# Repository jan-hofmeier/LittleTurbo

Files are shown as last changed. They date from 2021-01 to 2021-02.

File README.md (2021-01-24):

# Little Turbo

This card plugs into the co-processor slot of the Amiga 2000 and allows you to clock your 68000 or 68010 at 14Mhz. It also supports 2MB of SRAM of wich up to 1.75MB can be used as Fast Ranger RAM, like the Memory card of the original German A2000. The SRAM can run at the full 14Mhz with zero wait states.
It can also serve just as an Memory Expansion, without the 14Mhz stuff. In this case the CPU can stay in the sockel of the mainboard
The memory is mapped at `$C0000`. If you have a Rev. 4 B2000 this will overlap the onboard 512K "Slow RAM". 
The unused Part of the 2MB of SRAM can be used to emulate a Kickstart ROM up to 1MB.

The Layout of the Slot Connector was taken from SukkoPera OpenAmiga2000CoproAdapter

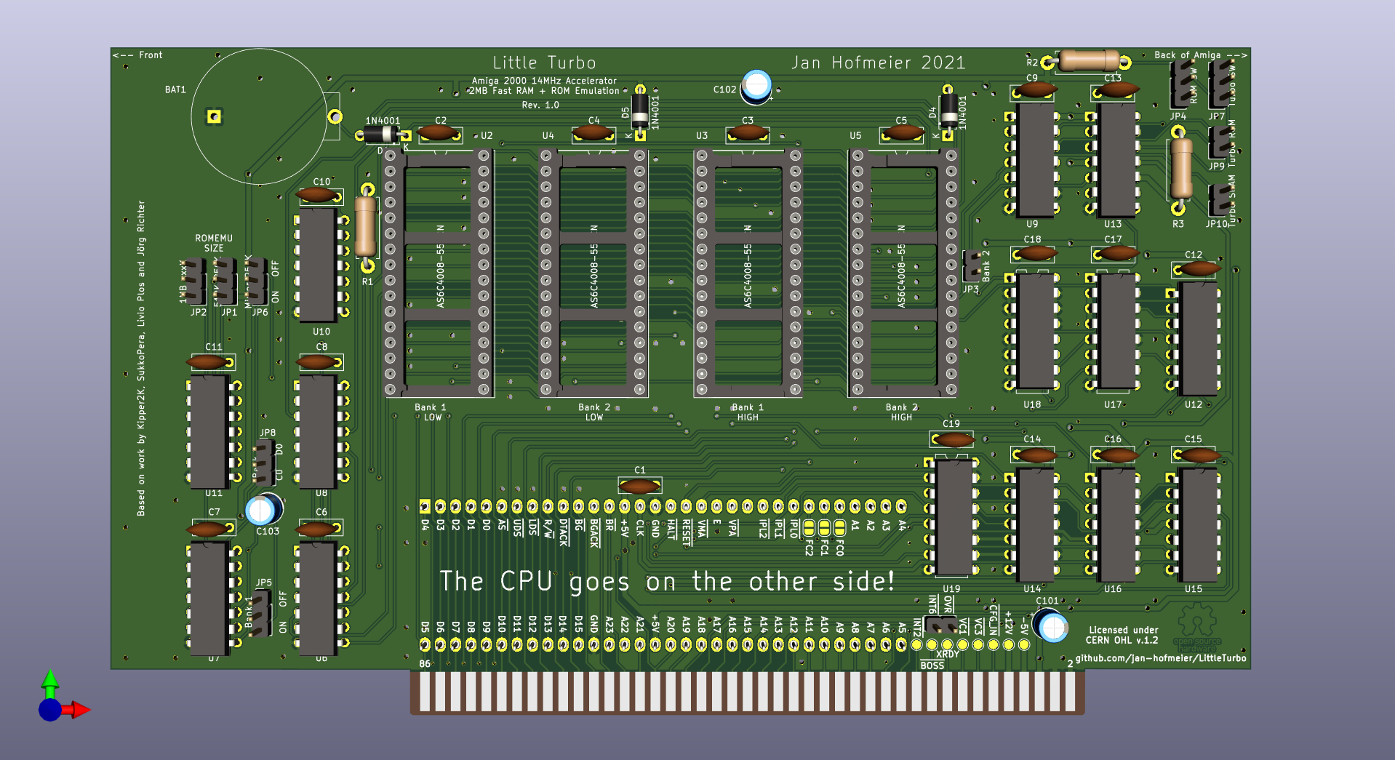
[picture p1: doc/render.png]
Board


### State of the Project

The PCB is done, next up is verifying that it works as intended.

### Installation
**Please be very careful when plugging this board** in the co-processor slot: there is an arrow on the board, **it must point to the back of the Amiga**. Plugging this adapter backwards will damage your CPU/accelerator card, as some pins of the CPU slot carry +12V!

### Parts
https://www.digikey.de/short/4795fv

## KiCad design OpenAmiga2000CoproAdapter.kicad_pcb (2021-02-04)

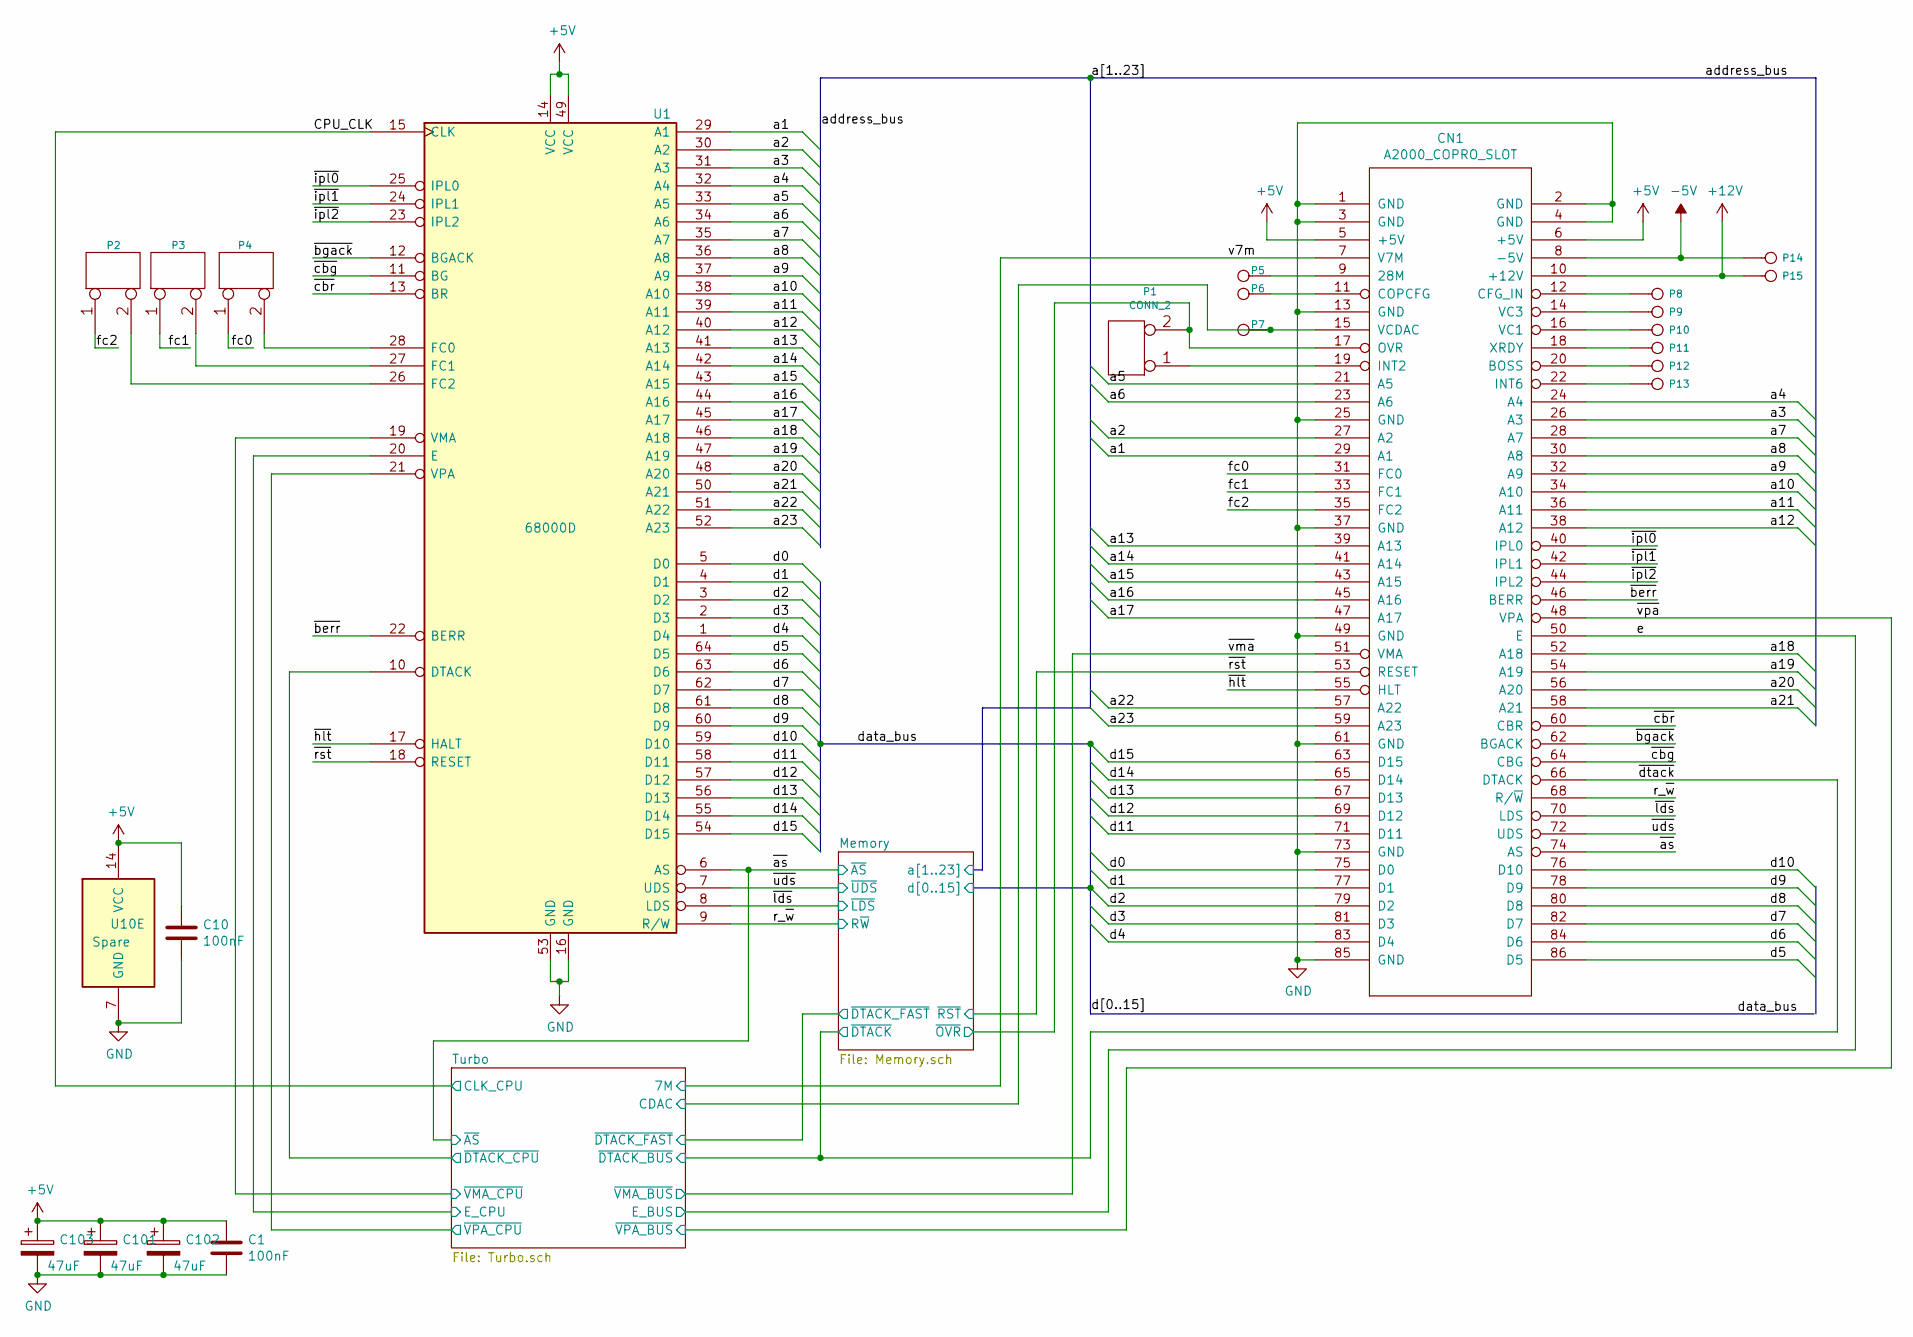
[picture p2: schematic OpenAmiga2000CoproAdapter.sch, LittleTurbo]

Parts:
C1, C10: 100nF; C_Disc_D7.0mm_W2.5mm_P5.00mm
C101, C102, C103: 47uF; CP_Radial_D5.0mm_P2.50mm
CN1: A2000_COPRO_SLOT
P1: CONN_2; PinHeader_1x02_P2.54mm_Vertical
P2, P3, P4: CONN_2; SolderJumper-2_P1.3mm_Open_RoundedPad1.0x1.5mm
P5, P6, P7, P8, P9, P10, P11, P12, P13, P14, P15: CONN_1; TestPoint_Pad_D1.5mm
U1: 68000D; DIP-64_W22.86mm_Socket_LongPads
U10: Spare; DIP-14_W7.62mm

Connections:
+5V: C1.1, C10.1, C101.1, C102.1, C103.1, CN1.5 (+5V), CN1.6 (+5V), U1.14 (VCC), U1.49 (VCC), U10.14 (VCC); also elsewhere on the board
+12V: CN1.10 (+12V), P15.1
-5V: CN1.8 (-5V), P14.1
/CPU_CLK: U1.15 (CLK); also elsewhere on the board
/Memory/~OVR: CN1.17 (OVR), P1.2 (PM); also elsewhere on the board
/Turbo/CDAC: CN1.15 (VCDAC), P7.1; also elsewhere on the board
/Turbo/E_CPU: U1.20 (E); also elsewhere on the board
/Turbo/~DTACK_CPU: U1.10 (DTACK); also elsewhere on the board
/Turbo/~VMA_CPU: U1.19 (VMA); also elsewhere on the board
/Turbo/~VPA_CPU: U1.21 (VPA); also elsewhere on the board
/a1: CN1.29 (A1), U1.29 (A1); also elsewhere on the board
/a2: CN1.27 (A2), U1.30 (A2); also elsewhere on the board
/a3: CN1.26 (A3), U1.31 (A3); also elsewhere on the board
/a4: CN1.24 (A4), U1.32 (A4); also elsewhere on the board
/a5: CN1.21 (A5), U1.33 (A5); also elsewhere on the board
/a6: CN1.23 (A6), U1.34 (A6); also elsewhere on the board
/a7: CN1.28 (A7), U1.35 (A7); also elsewhere on the board
/a8: CN1.30 (A8), U1.36 (A8); also elsewhere on the board
/a9: CN1.32 (A9), U1.37 (A9); also elsewhere on the board
/a10: CN1.34 (A10), U1.38 (A10); also elsewhere on the board
/a11: CN1.36 (A11), U1.39 (A11); also elsewhere on the board
/a12: CN1.38 (A12), U1.40 (A12); also elsewhere on the board
/a13: CN1.39 (A13), U1.41 (A13); also elsewhere on the board
/a14: CN1.41 (A14), U1.42 (A14); also elsewhere on the board
/a15: CN1.43 (A15), U1.43 (A15); also elsewhere on the board
/a16: CN1.45 (A16), U1.44 (A16); also elsewhere on the board
/a17: CN1.47 (A17), U1.45 (A17); also elsewhere on the board
/a18: CN1.52 (A18), U1.46 (A18); also elsewhere on the board
/a19: CN1.54 (A19), U1.47 (A19); also elsewhere on the board
/a20: CN1.56 (A20), U1.48 (A20); also elsewhere on the board
/a21: CN1.58 (A21), U1.50 (A21); also elsewhere on the board
/a22: CN1.57 (A22), U1.51 (A22); also elsewhere on the board
/a23: CN1.59 (A23), U1.52 (A23); also elsewhere on the board
/d0: CN1.75 (D0), U1.5 (D0); also elsewhere on the board
/d1: CN1.77 (D1), U1.4 (D1); also elsewhere on the board
/d2: CN1.79 (D2), U1.3 (D2); also elsewhere on the board
/d3: CN1.81 (D3), U1.2 (D3); also elsewhere on the board
/d4: CN1.83 (D4), U1.1 (D4); also elsewhere on the board
/d5: CN1.86 (D5), U1.64 (D5); also elsewhere on the board
/d6: CN1.84 (D6), U1.63 (D6); also elsewhere on the board
/d7: CN1.82 (D7), U1.62 (D7); also elsewhere on the board
/d8: CN1.80 (D8), U1.61 (D8); also elsewhere on the board
/d9: CN1.78 (D9), U1.60 (D9); also elsewhere on the board
/d10: CN1.76 (D10), U1.59 (D10); also elsewhere on the board
/d11: CN1.71 (D11), U1.58 (D11); also elsewhere on the board
/d12: CN1.69 (D12), U1.57 (D12); also elsewhere on the board
/d13: CN1.67 (D13), U1.56 (D13); also elsewhere on the board
/d14: CN1.65 (D14), U1.55 (D14); also elsewhere on the board
/d15: CN1.63 (D15), U1.54 (D15); also elsewhere on the board
/e: CN1.50 (E); also elsewhere on the board
/fc0: CN1.31 (FC0), P4.1
/fc1: CN1.33 (FC1), P3.1
/fc2: CN1.35 (FC2), P2.1
/r_~w: CN1.68 (R/~W), U1.9 (R/W); also elsewhere on the board
/v7m: CN1.7 (V7M); also elsewhere on the board
/~as: CN1.74 (AS), U1.6 (AS); also elsewhere on the board
/~berr: CN1.46 (BERR), U1.22 (BERR)
/~bgack: CN1.62 (BGACK), U1.12 (BGACK)
/~cbg: CN1.64 (CBG), U1.11 (BG)
/~cbr: CN1.60 (CBR), U1.13 (BR)
/~dtack: CN1.66 (DTACK); also elsewhere on the board
/~hlt: CN1.55 (HLT), U1.17 (HALT)
/~ipl0: CN1.40 (IPL0), U1.25 (IPL0)
/~ipl1: CN1.42 (IPL1), U1.24 (IPL1)
/~ipl2: CN1.44 (IPL2), U1.23 (IPL2)
/~lds: CN1.70 (LDS), U1.8 (LDS); also elsewhere on the board
/~rst: CN1.53 (RESET), U1.18 (RESET); also elsewhere on the board
/~uds: CN1.72 (UDS), U1.7 (UDS); also elsewhere on the board
/~vma: CN1.51 (VMA); also elsewhere on the board
/~vpa: CN1.48 (VPA); also elsewhere on the board
GND: C1.2, C10.2, C101.2, C102.2, C103.2, CN1.1 (GND), CN1.2 (GND), CN1.3 (GND), CN1.4 (GND), CN1.13 (GND), CN1.25 (GND), CN1.37 (GND), CN1.49 (GND), CN1.61 (GND), CN1.73 (GND), CN1.85 (GND), U1.16 (GND), U1.53 (GND), U10.7 (GND); also elsewhere on the board
unnamed: CN1.9 (28M), P5.1
unnamed: CN1.11 (COPCFG), P6.1
unnamed: CN1.12 (CFG_IN), P8.1
unnamed: CN1.14 (VC3), P9.1
unnamed: CN1.16 (VC1), P10.1
unnamed: CN1.18 (XRDY), P11.1
unnamed: CN1.19 (INT2), P1.1
unnamed: CN1.20 (BOSS), P12.1
unnamed: CN1.22 (INT6), P13.1
unnamed: P2.2 (PM), U1.26 (FC2)
unnamed: P3.2 (PM), U1.27 (FC1)
unnamed: P4.2 (PM), U1.28 (FC0)

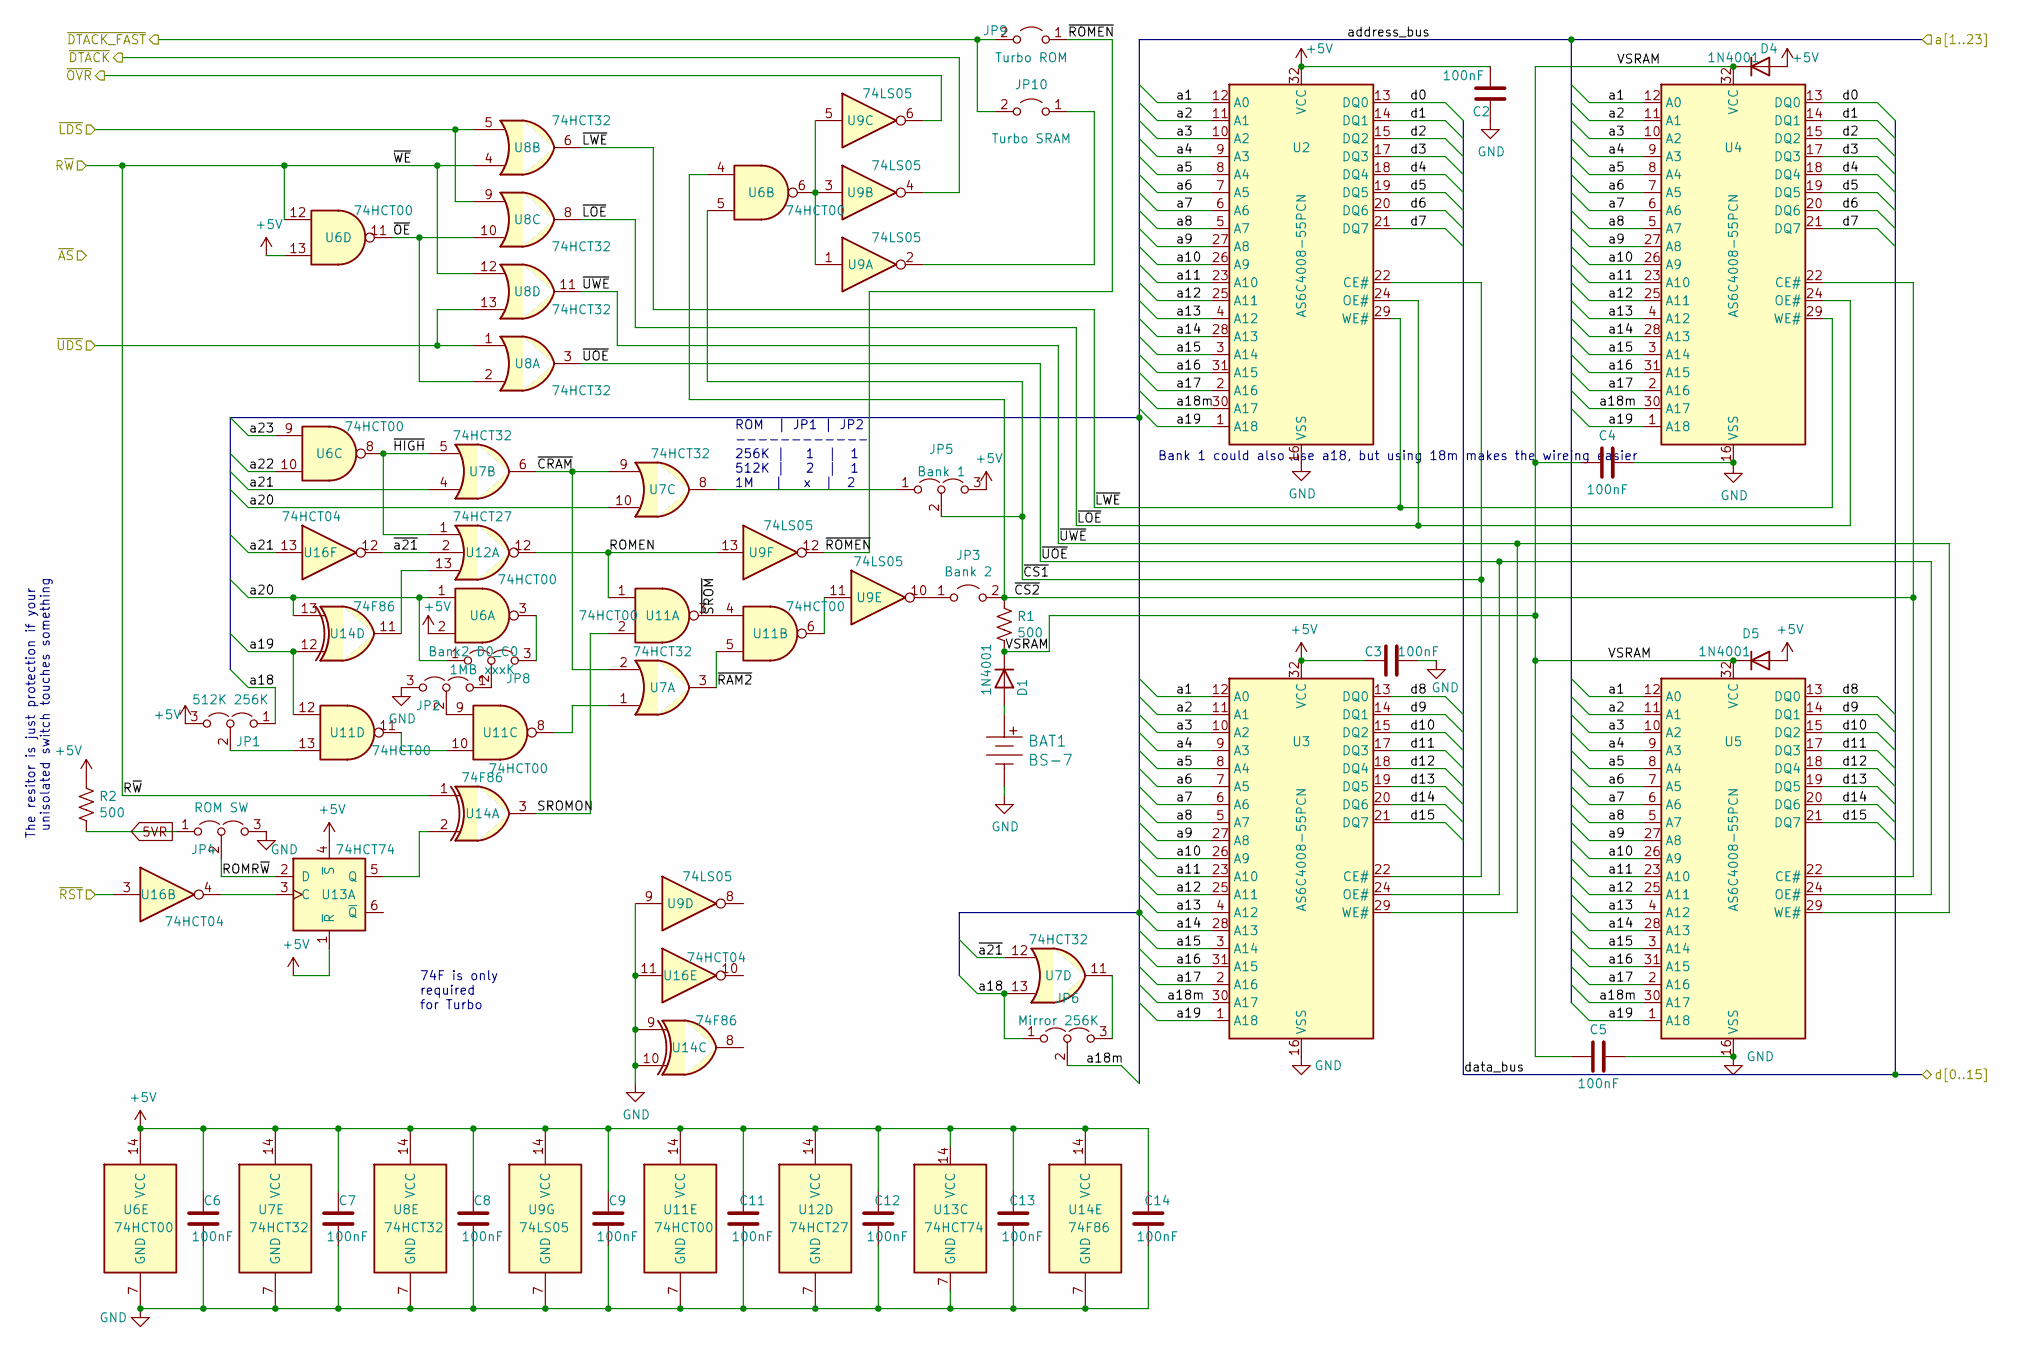
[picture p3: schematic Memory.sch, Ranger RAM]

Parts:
BAT1: BS-7; Battery_Holder_Coin_2032_BS-7; MPN BS-7; Digi-Key_PN BS-7-ND
C2, C3, C4, C5, C6, C7, C8, C9, C11, C12, C13, C14: 100nF; C_Disc_D7.0mm_W2.5mm_P5.00mm
D1, D4, D5: 1N4001; D_A-405_P7.62mm_Horizontal
JP1: 512K 256K; PinHeader_1x03_P2.54mm_Vertical
JP2: 1MB xxxK; PinHeader_1x03_P2.54mm_Vertical
JP3: Bank 2; PinHeader_1x02_P2.54mm_Vertical
JP4: ROM SW; PinHeader_1x03_P2.54mm_Vertical
JP5: Bank 1; PinHeader_1x03_P2.54mm_Vertical
JP6: Mirror 256K; PinHeader_1x03_P2.54mm_Vertical
JP8: Bank2 D0_C0; PinHeader_1x03_P2.54mm_Vertical
JP9: Turbo ROM; PinHeader_1x02_P2.54mm_Vertical
JP10: Turbo SRAM; PinHeader_1x02_P2.54mm_Vertical
R1, R2: 500; R_Axial_DIN0411_L9.9mm_D3.6mm_P12.70mm_Horizontal
U2, U3, U4, U5: AS6C4008-55PCN; DIP-32_W15.24mm_Socket
U6, U11: 74HCT00; DIP-14_W7.62mm
U7, U8: 74HCT32; DIP-14_W7.62mm
U9: 74LS05; DIP-14_W7.62mm
U12: 74HCT27; DIP-14_W7.62mm
U13: 74HCT74; DIP-14_W7.62mm
U14: 74F86; DIP-14_W7.62mm
U16: 74HCT04; DIP-14_W7.62mm

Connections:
5VR: JP4.1 (A), R2.2; also elsewhere on the board
+5V: C2.2, C3.2, C6.1, C7.1, C8.1, C9.1, C11.1, C12.1, C13.1, C14.1, D4.2 (A), D5.2 (A), JP1.3 (B), JP5.3 (B), R2.1, U2.32 (VCC), U3.32 (VCC), U6.2, U6.13, U6.14 (VCC), U7.14 (VCC), U8.14 (VCC), U9.14 (VCC), U11.14 (VCC), U12.14 (VCC), U13.1 (~R), U13.4 (~S), U13.14 (VCC), U14.14 (VCC); also elsewhere on the board
/Memory/ROMEN: U9.13, U11.1, U12.12
/Memory/ROMR~W: JP4.2 (C), U13.2 (D)
/Memory/SROMON: U11.2, U14.3
/Memory/VSRAM: C4.2, C5.2, D1.1 (K), D4.1 (K), D5.1 (K), R1.2, U4.32 (VCC), U5.32 (VCC)
/Memory/a18m: JP6.2 (C), U2.30 (A17), U3.30 (A17), U4.30 (A17), U5.30 (A17)
/Memory/~CRAM: U7.2, U7.6, U7.9
/Memory/~CS1: JP5.2 (C), U2.22 (CE#), U3.22 (CE#), U6.5
/Memory/~CS2: JP3.2 (B), R1.1, U4.22 (CE#), U5.22 (CE#), U6.4
/Memory/~DTACK_FAST: JP9.2 (B), JP10.2 (B); also elsewhere on the board
/Memory/~HIGH: U6.8, U7.5, U12.1
/Memory/~LOE: U2.24 (OE#), U4.24 (OE#), U8.8
/Memory/~LWE: U2.29 (WE#), U4.29 (WE#), U8.6
/Memory/~OE: U6.11, U8.2, U8.10
/Memory/~OVR: U9.6; also elsewhere on the board
/Memory/~RAM2: U7.3, U11.5
/Memory/~ROMEN: JP9.1 (A), U9.12
/Memory/~SROM: U11.3, U11.4
/Memory/~UOE: U3.24 (OE#), U5.24 (OE#), U8.3
/Memory/~UWE: U3.29 (WE#), U5.29 (WE#), U8.11
/Memory/~a21: U7.12, U12.2, U16.12
/a1: U2.12 (A0), U3.12 (A0), U4.12 (A0), U5.12 (A0); also elsewhere on the board
/a2: U2.11 (A1), U3.11 (A1), U4.11 (A1), U5.11 (A1); also elsewhere on the board
/a3: U2.10 (A2), U3.10 (A2), U4.10 (A2), U5.10 (A2); also elsewhere on the board
/a4: U2.9 (A3), U3.9 (A3), U4.9 (A3), U5.9 (A3); also elsewhere on the board
/a5: U2.8 (A4), U3.8 (A4), U4.8 (A4), U5.8 (A4); also elsewhere on the board
/a6: U2.7 (A5), U3.7 (A5), U4.7 (A5), U5.7 (A5); also elsewhere on the board
/a7: U2.6 (A6), U3.6 (A6), U4.6 (A6), U5.6 (A6); also elsewhere on the board
/a8: U2.5 (A7), U3.5 (A7), U4.5 (A7), U5.5 (A7); also elsewhere on the board
/a9: U2.27 (A8), U3.27 (A8), U4.27 (A8), U5.27 (A8); also elsewhere on the board
/a10: U2.26 (A9), U3.26 (A9), U4.26 (A9), U5.26 (A9); also elsewhere on the board
/a11: U2.23 (A10), U3.23 (A10), U4.23 (A10), U5.23 (A10); also elsewhere on the board
/a12: U2.25 (A11), U3.25 (A11), U4.25 (A11), U5.25 (A11); also elsewhere on the board
/a13: U2.4 (A12), U3.4 (A12), U4.4 (A12), U5.4 (A12); also elsewhere on the board
/a14: U2.28 (A13), U3.28 (A13), U4.28 (A13), U5.28 (A13); also elsewhere on the board
/a15: U2.3 (A14), U3.3 (A14), U4.3 (A14), U5.3 (A14); also elsewhere on the board
/a16: U2.31 (A15), U3.31 (A15), U4.31 (A15), U5.31 (A15); also elsewhere on the board
/a17: U2.2 (A16), U3.2 (A16), U4.2 (A16), U5.2 (A16); also elsewhere on the board
/a18: JP1.1 (A), JP6.1 (A), U7.13; also elsewhere on the board
/a19: U2.1 (A18), U3.1 (A18), U4.1 (A18), U5.1 (A18), U11.12, U14.12; also elsewhere on the board
/a20: JP8.1 (A), U6.1, U7.10, U14.13; also elsewhere on the board
/a21: U7.4, U16.13; also elsewhere on the board
/a22: U6.10; also elsewhere on the board
/a23: U6.9; also elsewhere on the board
/d0: U2.13 (DQ0), U4.13 (DQ0); also elsewhere on the board
/d1: U2.14 (DQ1), U4.14 (DQ1); also elsewhere on the board
/d2: U2.15 (DQ2), U4.15 (DQ2); also elsewhere on the board
/d3: U2.17 (DQ3), U4.17 (DQ3); also elsewhere on the board
/d4: U2.18 (DQ4), U4.18 (DQ4); also elsewhere on the board
/d5: U2.19 (DQ5), U4.19 (DQ5); also elsewhere on the board
/d6: U2.20 (DQ6), U4.20 (DQ6); also elsewhere on the board
/d7: U2.21 (DQ7), U4.21 (DQ7); also elsewhere on the board
/d8: U3.13 (DQ0), U5.13 (DQ0); also elsewhere on the board
/d9: U3.14 (DQ1), U5.14 (DQ1); also elsewhere on the board
/d10: U3.15 (DQ2), U5.15 (DQ2); also elsewhere on the board
/d11: U3.17 (DQ3), U5.17 (DQ3); also elsewhere on the board
/d12: U3.18 (DQ4), U5.18 (DQ4); also elsewhere on the board
/d13: U3.19 (DQ5), U5.19 (DQ5); also elsewhere on the board
/d14: U3.20 (DQ6), U5.20 (DQ6); also elsewhere on the board
/d15: U3.21 (DQ7), U5.21 (DQ7); also elsewhere on the board
/r_~w: U6.12, U8.4, U8.12, U14.1; also elsewhere on the board
/~dtack: U9.4; also elsewhere on the board
/~lds: U8.5, U8.9; also elsewhere on the board
/~rst: U16.3; also elsewhere on the board
/~uds: U8.1, U8.13; also elsewhere on the board
GND: BAT1.Neg, C2.1, C3.1, C4.1, C5.1, C6.2, C7.2, C8.2, C9.2, C11.2, C12.2, C13.2, C14.2, JP2.3 (B), JP4.3 (B), U2.16 (VSS), U3.16 (VSS), U4.16 (VSS), U5.16 (VSS), U6.7 (GND), U7.7 (GND), U8.7 (GND), U9.7 (GND), U9.9, U11.7 (GND), U12.7 (GND), U13.7 (GND), U14.7 (GND), U14.9, U14.10, U16.11; also elsewhere on the board
unnamed: BAT1.Pos, D1.2 (A)
unnamed: JP1.2 (C), U11.13
unnamed: JP2.1 (A), JP8.2 (C)
unnamed: JP2.2 (C), U11.9
unnamed: JP3.1 (A), U9.10
unnamed: JP5.1 (A), U7.8
unnamed: JP6.3 (B), U7.11
unnamed: JP8.3 (B), U6.3
unnamed: JP10.1 (A), U9.2
unnamed: U6.6, U9.1, U9.3, U9.5
unnamed: U9.11, U11.6
unnamed: U7.1, U11.8
unnamed: U11.10, U11.11
unnamed: U12.13, U14.11
unnamed: U13.3 (C), U16.4
unnamed: U13.5 (Q), U14.2

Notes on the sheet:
ROM | JP1 | JP2 ------------ 256K | 1 | 1 512K | 2 | 1 1M | x | 2
Bank 1 could also use a18, but using 18m makes the wireing easier
74F is only required for Turbo
The resitor is just protection if your unisolated switch touches something

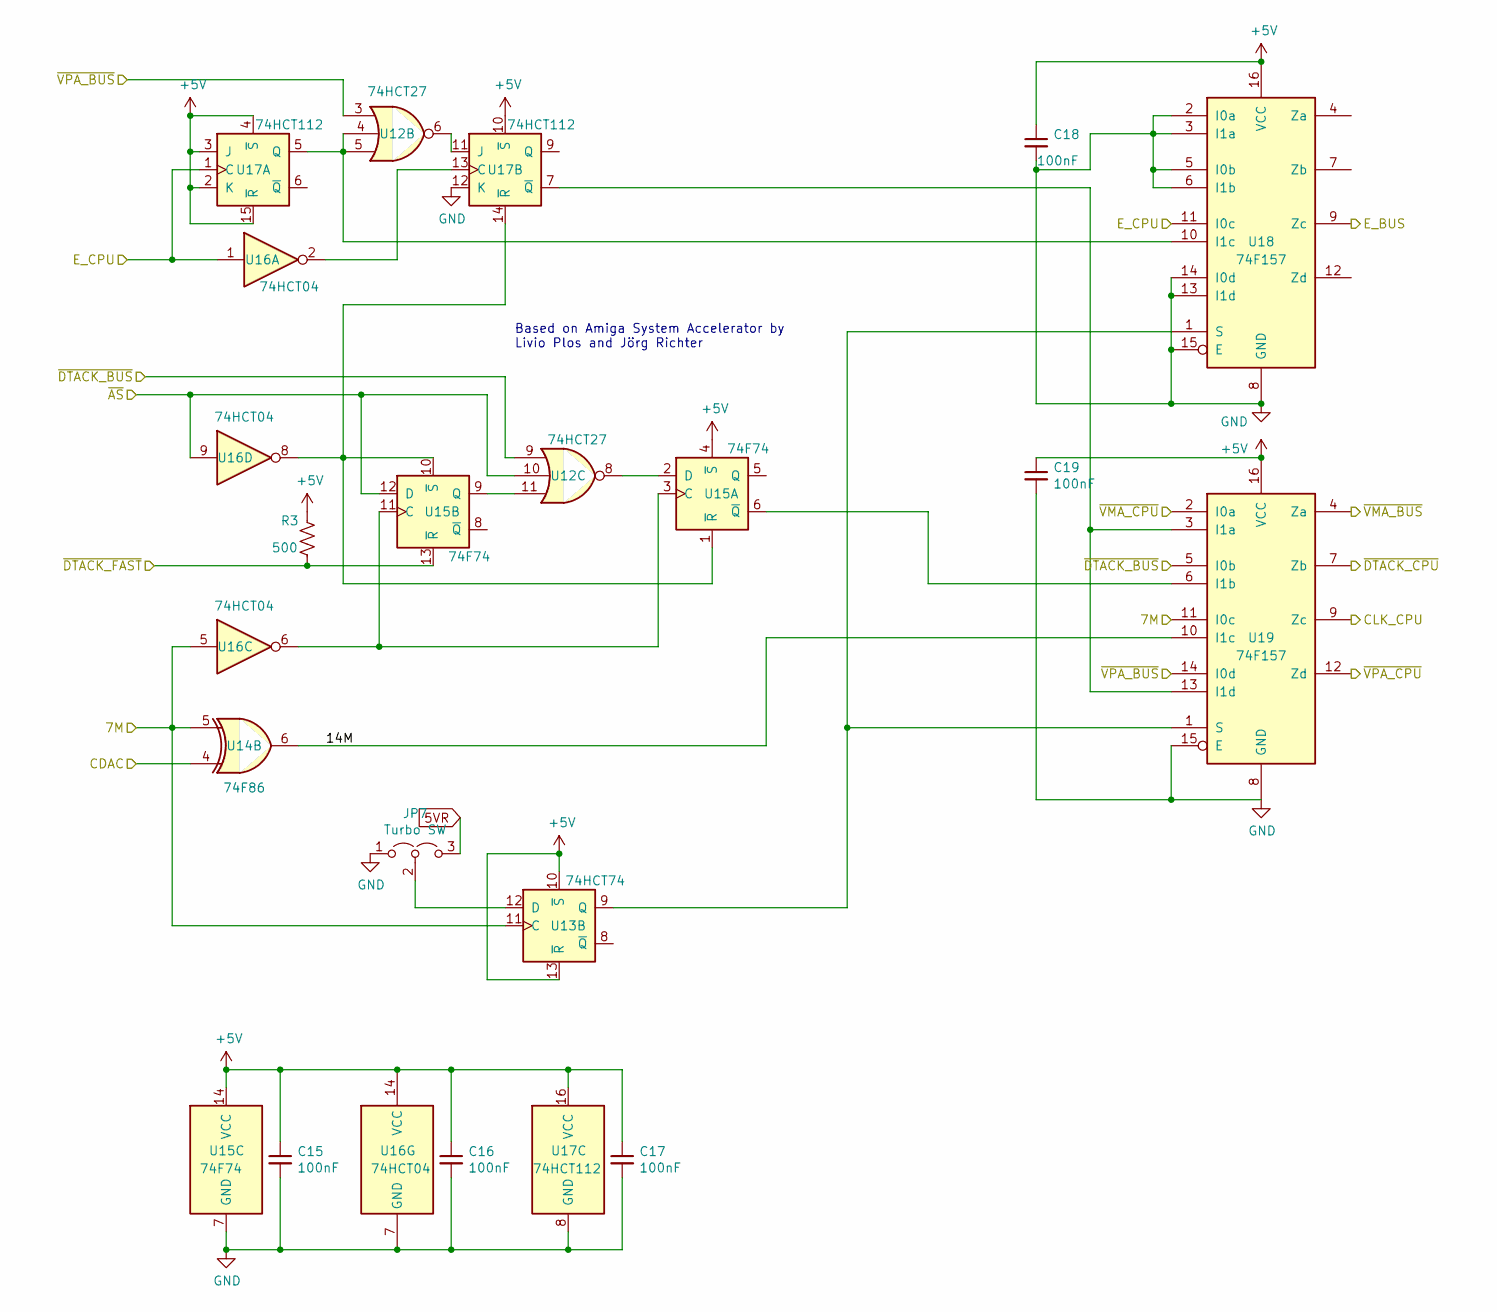
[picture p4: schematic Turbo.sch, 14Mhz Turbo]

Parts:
C15, C16, C17, C18, C19: 100nF; C_Disc_D7.0mm_W2.5mm_P5.00mm
JP7: Turbo SW; PinHeader_1x03_P2.54mm_Vertical
R3: 500; R_Axial_DIN0411_L9.9mm_D3.6mm_P12.70mm_Horizontal
U12: 74HCT27; DIP-14_W7.62mm
U13: 74HCT74; DIP-14_W7.62mm
U14: 74F86; DIP-14_W7.62mm
U15: 74F74; DIP-14_W7.62mm
U16: 74HCT04; DIP-14_W7.62mm
U17: 74HCT112; DIP-16_W7.62mm
U18, U19: 74F157; DIP-16_W7.62mm

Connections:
5VR: JP7.3 (B); also elsewhere on the board
+5V: C15.1, C16.1, C17.1, C18.1, C19.1, R3.1, U13.10 (~S), U13.13 (~R), U15.4 (~S), U15.14 (VCC), U16.14 (VCC), U17.2 (K), U17.3 (J), U17.4 (~S), U17.10 (~S), U17.15 (~R), U17.16 (VCC), U18.16 (VCC), U19.16 (VCC); also elsewhere on the board
/CPU_CLK: U19.9 (Zc); also elsewhere on the board
/Memory/~DTACK_FAST: R3.2, U15.13 (~R); also elsewhere on the board
/Turbo/14M: U14.6, U19.10 (I1c)
/Turbo/CDAC: U14.4; also elsewhere on the board
/Turbo/E_CPU: U16.1, U17.1 (C), U18.11 (I0c); also elsewhere on the board
/Turbo/~DTACK_CPU: U19.7 (Zb); also elsewhere on the board
/Turbo/~VMA_CPU: U19.2 (I0a); also elsewhere on the board
/Turbo/~VPA_CPU: U19.12 (Zd); also elsewhere on the board
/e: U18.9 (Zc); also elsewhere on the board
/v7m: U13.11 (C), U14.5, U16.5, U19.11 (I0c); also elsewhere on the board
/~as: U12.10, U15.12 (D), U16.9; also elsewhere on the board
/~dtack: U12.9, U19.5 (I0b); also elsewhere on the board
/~vma: U19.4 (Za); also elsewhere on the board
/~vpa: U12.3, U19.14 (I0d); also elsewhere on the board
GND: C15.2, C16.2, C17.2, C18.2, C19.2, JP7.1 (A), U15.7 (GND), U16.7 (GND), U17.8 (GND), U17.12 (K), U18.2 (I0a), U18.3 (I1a), U18.5 (I0b), U18.6 (I1b), U18.8 (GND), U18.13 (I1d), U18.14 (I0d), U18.15 (E), U19.8 (GND), U19.15 (E); also elsewhere on the board
unnamed: JP7.2 (C), U13.12 (D)
unnamed: U12.4, U12.5, U17.5 (Q), U18.10 (I1c)
unnamed: U12.6, U17.11 (J)
unnamed: U12.8, U15.2 (D)
unnamed: U12.11, U15.9 (Q)
unnamed: U13.9 (Q), U18.1 (S), U19.1 (S)
unnamed: U15.1 (~R), U15.10 (~S), U16.8, U17.14 (~R)
unnamed: U15.6 (~Q), U19.6 (I1b)
unnamed: U15.3 (C), U15.11 (C), U16.6
unnamed: U16.2, U17.13 (C)
unnamed: U17.7 (~Q), U19.3 (I1a), U19.13 (I1d)

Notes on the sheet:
Based on Amiga System Accelerator by Livio Plos and Jörg Richter

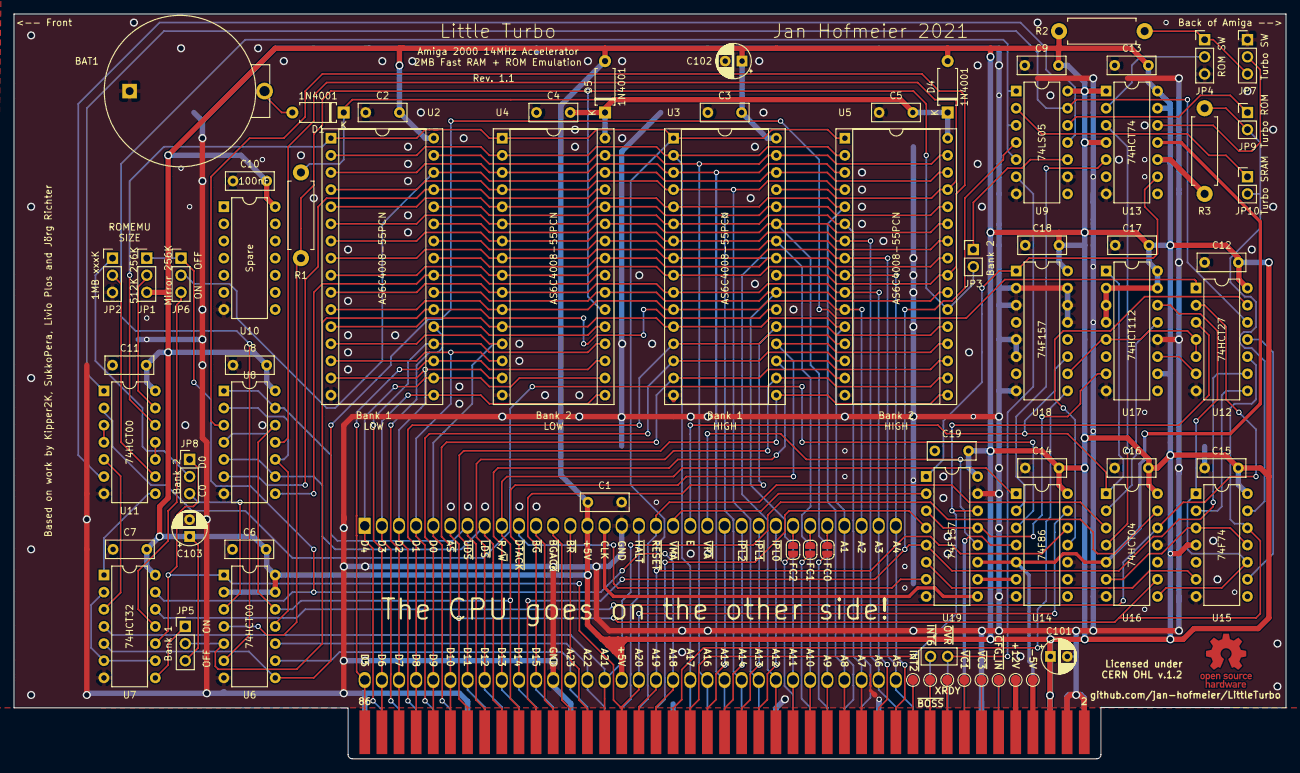
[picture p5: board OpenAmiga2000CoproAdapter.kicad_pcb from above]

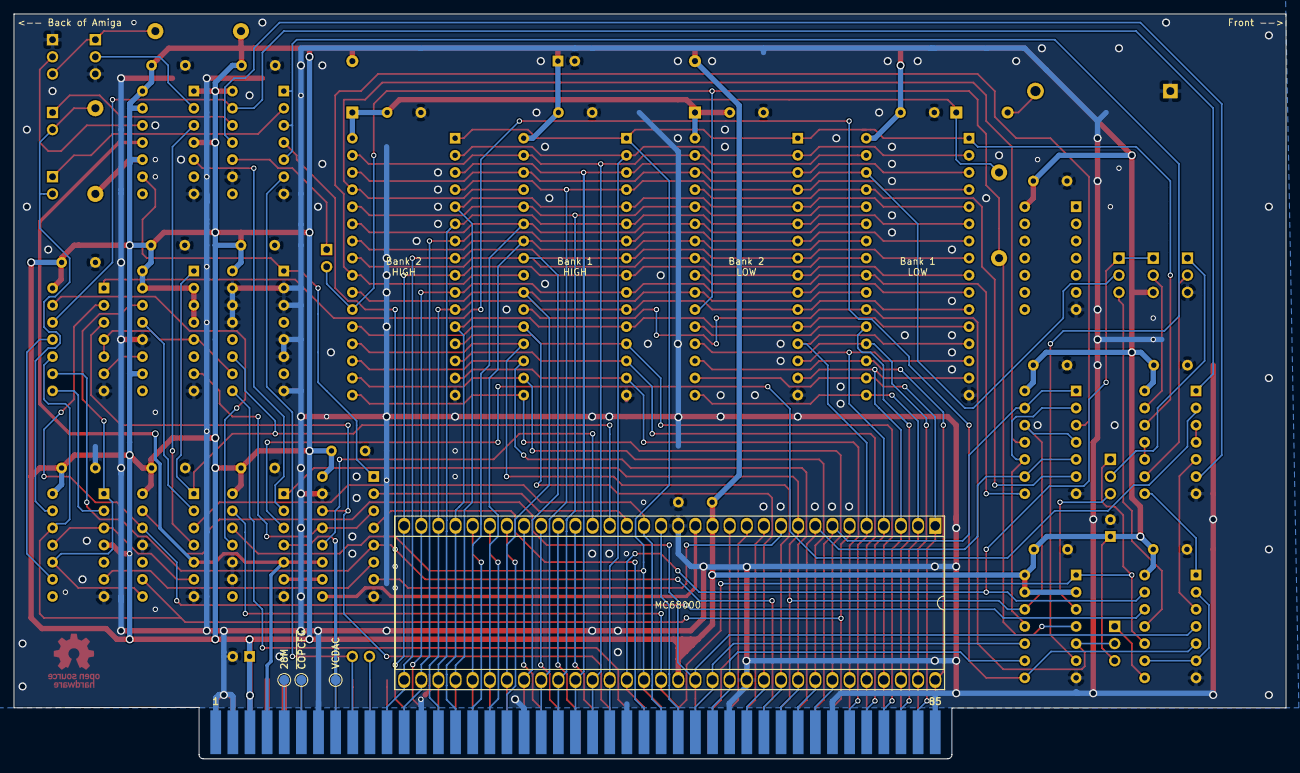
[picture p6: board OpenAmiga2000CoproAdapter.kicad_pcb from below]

Board: 2 copper layers, 188.6 x 110.4 mm, 75 parts (5 on the bottom side), 131 nets.

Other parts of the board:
P99: OSHW_LOGO; OSHW-Logo_7.5x8mm_Copper

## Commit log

2021-01-02 Memory bank 1
    [Memory.sch, OpenAmiga2000CoproAdapter.kicad_pcb, OpenAmiga2000CoproAdapter.sch]
2021-01-02 rearange stuff
    [Memory.sch]
2021-01-02 decode second bank
    [Memory.sch]
2021-01-02 rom emulation bank
    [Memory.sch]
2021-01-02 jumper for rom size
    [Memory.sch, OpenAmiga2000CoproAdapter.sch]
2021-01-02 swap upper and lower memory byte on pcb
    [OpenAmiga2000CoproAdapter.kicad_pcb]
2021-01-02 add battery
    [Memory.sch]
2021-01-02 more rearange
    [Memory.sch]
2021-01-03 ROM RW switch
    [Memory.sch]
2021-01-03 replace 2 ORs by 3 way OR to share the IC
    [Memory.sch]
2021-01-03 RST low active
    [Memory.sch]
2021-01-03 reorganize components for partial builds
    [Memory.sch, OpenAmiga2000CoproAdapter.kicad_pcb]
2021-01-03 add jumpers to disable memory banks
    [Memory.sch]
2021-01-03 remove wrong connection
    [Memory.sch]
2021-01-03 wire the jumper up correctly
    [Memory.sch]
2021-01-03 add jumper to map second bank at C0000
    [Memory.sch]
2021-01-04 cleaning up a bit more
    [Memory.sch]
2021-01-04 Turbo Sheet
    [Turbo.sch]
2021-01-04 finish turbo section
    [Memory.sch, OpenAmiga2000CoproAdapter.sch, Turbo.sch]
2021-01-04 component names
    [Memory.sch, OpenAmiga2000CoproAdapter.kicad_pcb, Turbo.sch]
2021-01-04 capacitors for memory
    [Memory.sch]
2021-01-04 add electrolytics
    [Memory.sch, OpenAmiga2000CoproAdapter.sch, Turbo.sch]
2021-01-04 sheet metadata
    [Memory.sch, OpenAmiga2000CoproAdapter.sch, Turbo.sch]
2021-01-04 assign footprints
    [Memory.sch, OpenAmiga2000CoproAdapter.sch, Turbo.sch]
2021-01-06 align to 10mil
    [OpenAmiga2000CoproAdapter.kicad_pcb]
2021-01-06 routed upper byte
    [Memory.sch, OpenAmiga2000CoproAdapter.kicad_pcb, OpenAmiga2000CoproAdapter.sch]
2021-01-07 new layout
    [OpenAmiga2000CoproAdapter.kicad_pcb]
2021-01-07 more routing
    [Memory.sch, OpenAmiga2000CoproAdapter.kicad_pcb]
2021-01-07 routed address decoding
    [Memory.sch, OpenAmiga2000CoproAdapter.kicad_pcb, OpenAmiga2000CoproAdapter.sch]
2021-01-08 turbo layout
    [Memory.sch, OpenAmiga2000CoproAdapter.kicad_pcb, Turbo.sch]
2021-01-08 finish routing
    [Memory.sch, OpenAmiga2000CoproAdapter.kicad_pcb, OpenAmiga2000CoproAdapter.sch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]
2021-01-08 add missing routes
    [OpenAmiga2000CoproAdapter.kicad_pcb]
2021-01-08 fill areas
    [OpenAmiga2000CoproAdapter.kicad_pcb]
2021-01-08 more ground
    [OpenAmiga2000CoproAdapter.kicad_pcb]
2021-01-09 fix unconnected
    [OpenAmiga2000CoproAdapter.kicad_pcb]
2021-01-09 fix drc warnings
    [OpenAmiga2000CoproAdapter.kicad_pcb]
2021-01-09 fix incorrect courtyard of connector
    [Memory.sch, OpenAmiga2000CoproAdapter.kicad_pcb]
2021-01-09 fix unconnected ground
    [OpenAmiga2000CoproAdapter.kicad_pcb]
2021-01-09 silk screen
    [Memory.sch, OpenAmiga2000CoproAdapter.kicad_pcb, OpenAmiga2000CoproAdapter.sch]
2021-01-10 rom mirror
    [Memory.sch, OpenAmiga2000CoproAdapter.kicad_pcb, OpenAmiga2000CoproAdapter.sch]
2021-01-10 dont mirror in lower 512k
    [Memory.sch, OpenAmiga2000CoproAdapter.kicad_pcb, Turbo.sch]
2021-01-10 fix connector and small stuff
    [OpenAmiga2000CoproAdapter.kicad_pcb]
2021-01-11 fix bug with using second bank at C0
    [Memory.sch, Turbo.sch]
2021-01-14 new adress decoding for bank2
    [Memory.sch]
2021-01-15 update routes
    [Memory.sch, OpenAmiga2000CoproAdapter.kicad_pcb]
2021-01-15 reorganize turbo jumpers
    [OpenAmiga2000CoproAdapter.kicad_pcb, Turbo.sch]
2021-01-15 fix connector
    [OpenAmiga2000CoproAdapter.kicad_pcb]
2021-01-15 update silk screen
    [OpenAmiga2000CoproAdapter.kicad_pcb]
2021-01-15 shrink board
    [OpenAmiga2000CoproAdapter.kicad_pcb]
2021-01-15 remove via
    [OpenAmiga2000CoproAdapter.kicad_pcb]
2021-01-15 move track
    [OpenAmiga2000CoproAdapter.kicad_pcb]
2021-01-15 add revision
    [OpenAmiga2000CoproAdapter.kicad_pcb]
2021-01-15 track clearence
    [OpenAmiga2000CoproAdapter.kicad_pcb]
2021-01-15 clean a few tracks
    [OpenAmiga2000CoproAdapter.kicad_pcb]
2021-01-16 fix 265k rom in schematics
    [Memory.sch]
2021-01-16 apply fix to pcb
    [OpenAmiga2000CoproAdapter.kicad_pcb]
2021-01-16 clean up
    [OpenAmiga2000CoproAdapter.kicad_pcb]
2021-01-16 remove explicit ground connections
    [OpenAmiga2000CoproAdapter.kicad_pcb]
2021-01-16 more cleanup
    [OpenAmiga2000CoproAdapter.kicad_pcb, Turbo.sch]
2021-01-16 add protection resistor
    [Memory.sch, OpenAmiga2000CoproAdapter.kicad_pcb, Turbo.sch]
2021-01-16 generate gerbers
    [OpenAmiga2000CoproAdapter.kicad_pcb]
2021-01-17 some minor stuff
    [Memory.sch, OpenAmiga2000CoproAdapter.kicad_pcb]
2021-01-17 updated gerbers
    [OpenAmiga2000CoproAdapter.kicad_pcb]
2021-01-18 use digikey battery holder
    [Memory.sch, OpenAmiga2000CoproAdapter.kicad_pcb, Turbo.sch]
2021-01-18 print component values on silk
    [OpenAmiga2000CoproAdapter.kicad_pcb]
2021-01-18 fix unconnected via
    [OpenAmiga2000CoproAdapter.kicad_pcb]
2021-01-19 remove a few vias via
    [OpenAmiga2000CoproAdapter.kicad_pcb]
2021-01-19 more via fixing
    [OpenAmiga2000CoproAdapter.kicad_pcb]
2021-02-03 fix silkscreen label
    [OpenAmiga2000CoproAdapter.kicad_pcb]
2021-02-04 fix uds lds mixup
    [Memory.sch, OpenAmiga2000CoproAdapter.kicad_pcb]
2021-02-04 turn jumper around so it matches silk screen
    [Memory.sch, OpenAmiga2000CoproAdapter.kicad_pcb]
2021-07-19 add Memory fixes to schematics
    [Memory.sch]
2021-07-19 generate 7M from cdac schematics
    [Memory.sch, Turbo.sch]
2021-07-19 use not cdac to invert 14M schematics
    [Turbo.sch]
2021-07-19 fix shee input schematics
    [OpenAmiga2000CoproAdapter.sch]
2021-07-21 new DTACK delay in schematics
    [Memory.sch, Turbo.sch]
2021-07-21 AS UDS LDS delay in schematics
    [Turbo.sch]
2021-07-24 delay BG
    [Turbo.sch]

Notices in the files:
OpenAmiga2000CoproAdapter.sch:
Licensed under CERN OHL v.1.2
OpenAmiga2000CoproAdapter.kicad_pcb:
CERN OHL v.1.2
